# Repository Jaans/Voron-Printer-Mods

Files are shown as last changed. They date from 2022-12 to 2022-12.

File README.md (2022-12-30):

# Voron-Printer-Mods
My collection Voron printer mods or related things.

* [Bouncy Mouse](./Bouncy-Mouse)

* [CAD Model for another Angry CAM OV5648 module](./AngryCAM-OV5648-A)

* [Gantry Chain Guide](./Gantry-Chain-Guide)

* [Purge Bucket - Whopping Remix](./Purge-Bucket-Fermio-On-Kinematic)

* [Sturdy Handles for clearing 6mm panels](./Sturdy-Handles)

## Disclaimer
Content in this repository are for my own use, and not specifically for public release and not for commercial gain. 

It probably contains multiple errors, and is subject to change without notice. 

If you use anything from the repository (which you are most welcome to do), you take responsibility for the outcomes and it is up to you to determine whether it is suitable or even safe. I give no warrantees and do not take responsibility for any of your actions.

In many instances, there are designs from of existing parts and may include copies of these in my repositories for the sake of convenience, but I have tried to link to the originals and give proper credit whenever I have done so. 

If you notice a part that I did not attribute properly, I assure you this this is an oversight and not an attempt to claim anyone's work as my own. Please let me know if you notice where I have failed to properly attribute and I will get that fixed as soon as possible!

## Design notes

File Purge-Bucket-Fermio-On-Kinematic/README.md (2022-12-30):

# Purge Bucket - Whopping Remix

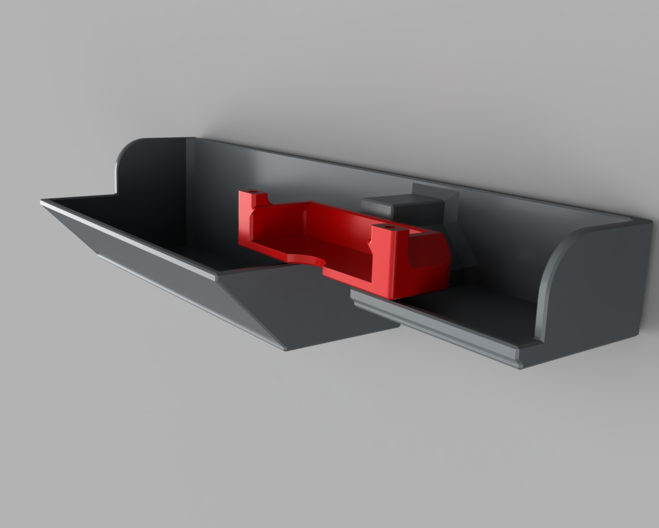
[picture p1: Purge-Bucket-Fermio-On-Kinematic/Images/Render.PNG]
Whopping Purge Bucket


These modifications are to fit my [Fermio Labs 350mmx350mm build plate](https://fermio.xyz/fermio-labs-gmbh/voron-build-plate-350-x-350-mm/) and [Whoppingpochard's Maxwell Kinematic mounts](https://uniqueprints.shop/shop/voron-2-4/voron-2-4-kinematic-bed-mount/) (Thanks @JACKT).

The CADs are shamefully adapted from the bucket design by [Dr. Dave](https://github.com/Dfdye/Voron_Mods/tree/main/Purge_Bucket_for_WP_Kinetic_Mount). 

For some reason his design didn't quite fit my setup anymore when I had to move things around a little to physically accommodate the Y offset induced by [Voron TAP](https://github.com/VoronDesign/Voron-Tap).

So, I modified them to fit.

# Models
Look in the [CAD](CAD/) and [STL](STL/) folders for the Fusion360 design and the resulting STL model.

# Build
Followed the original repo's guide.

### Printed in Polymaker PolyLite ABS.
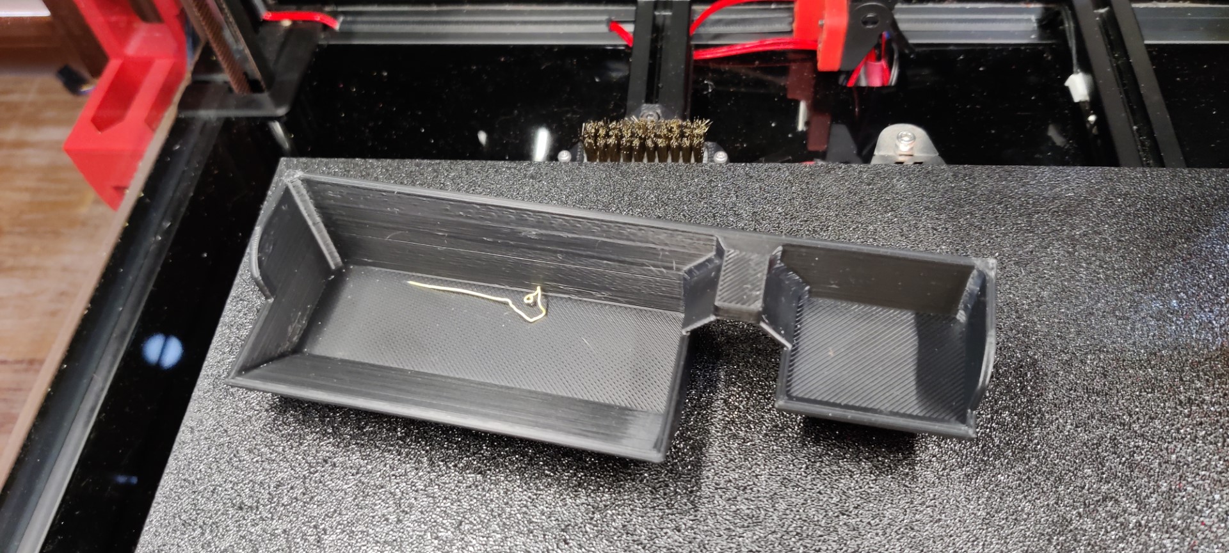
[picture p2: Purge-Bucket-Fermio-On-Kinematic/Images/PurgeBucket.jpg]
Printed


### MAG-ed and Loaded!
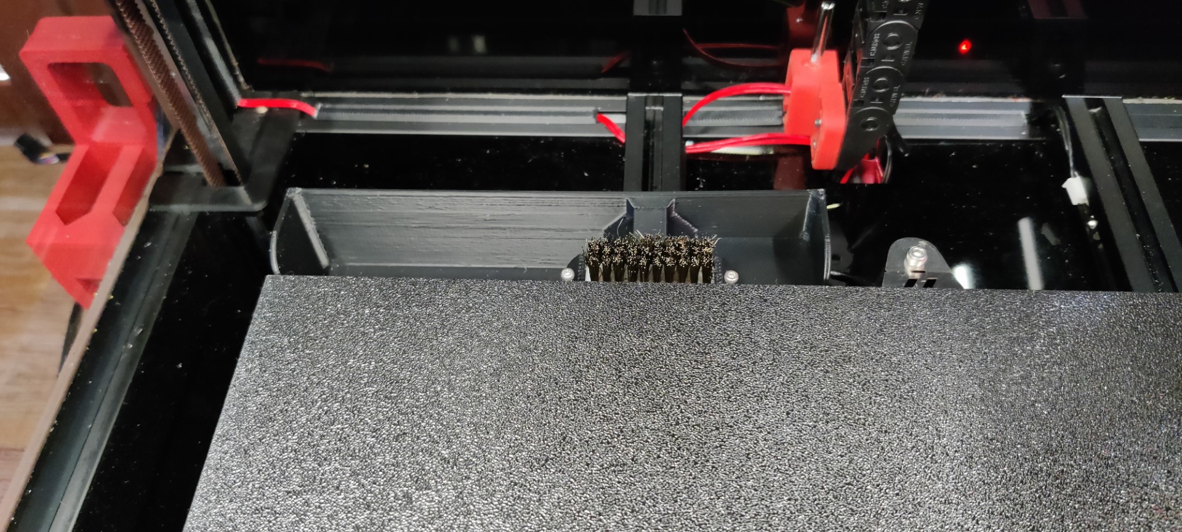
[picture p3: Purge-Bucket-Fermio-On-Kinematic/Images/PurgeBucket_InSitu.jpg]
In Situ


# Attribution
All credit goes to `Dr. Dave` and his repo over at https://github.com/Dfdye/Voron_Mods/tree/main/Purge_Bucket_for_WP_Kinetic_Mount

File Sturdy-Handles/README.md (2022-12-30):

# A 8.5mm version of Jeoje's excellent sturdy handles for my Voron v2
Replaced my panels with 6mm thick Acrylic versions and this meant that the existing [`Sturdy Handles by Jeoje'](https://github.com/VoronDesign/VoronUsers/tree/master/printer_mods/jeoje/Sturdy_Handles) didn't fit anymore :-(

So, modified them from 6mm to 8.5mm which in turn allows for clearance of 6mm panels.
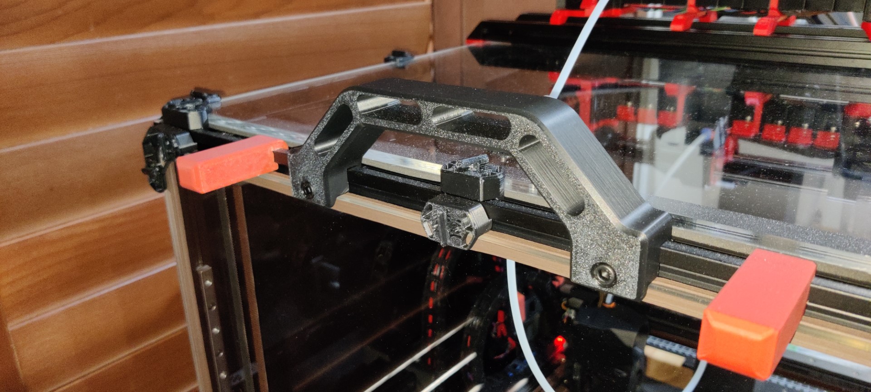
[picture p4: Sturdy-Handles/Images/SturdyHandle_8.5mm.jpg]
8.5mm Sturdy Handles


# Models
Look in the [CAD](CAD/) and [STL](STL/) folders for the Fusion360 design and the resulting STL model.

# Build
Followed the original repo's guide.
Printed in ABS with higher infill than usual, for strength.

# Attribution
All credit goes to `Joeje` and his repo over at https://github.com/VoronDesign/VoronUsers/tree/master/printer_mods/jeoje/Sturdy_Handles

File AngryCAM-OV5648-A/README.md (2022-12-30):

# Another OV5648 front cover design for Angry CAM USB

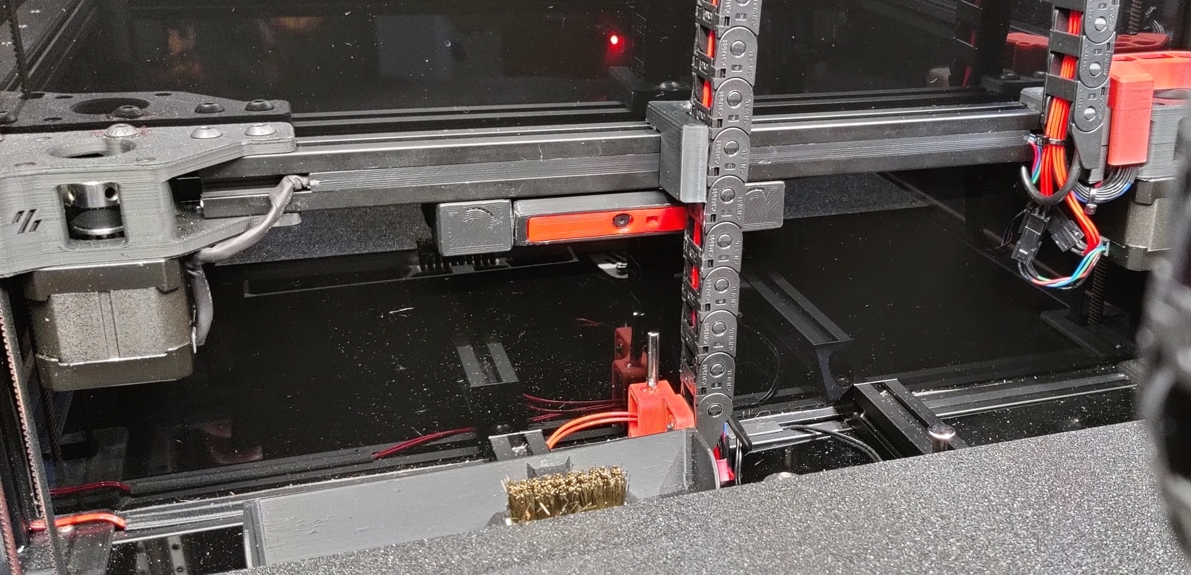
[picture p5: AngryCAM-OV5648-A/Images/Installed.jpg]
OV5648 Installed


# Camera Component Layout
There are various manufacturers of USB "stick cameras" like those for the OV5640 / OV5648 USB cameras. This repo contains CAD and STLs for fitting the layout of one of these:
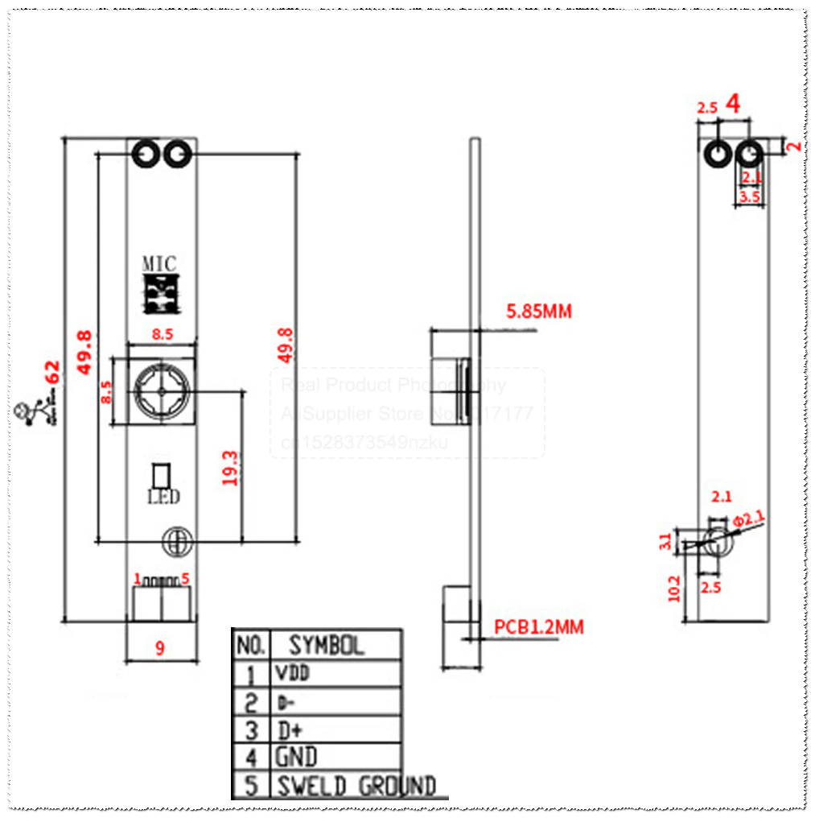
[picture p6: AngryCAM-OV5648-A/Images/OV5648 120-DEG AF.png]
OV5648 Layout


# Hardware
- The AliExpress vendor link I used was (no affiliation): 
https://www.aliexpress.com/item/1005003833993617.html?spm=a2g0o.order_list.order_list_main.5.70ce1802KScJvA

# Models
Look in the [CAD](CAD/) and [STL](STL/) folders for the Fusion360 design and the resulting STL model.

# Build

Printed in ABS to withstand the heat of my chamber.

Used default print settings, as per `#chri.kai.in`'s original [repo](https://github.com/VoronDesign/VoronUsers/tree/master/printer_mods/chri.kai.in/Angry_CAM_USB).

Side view showing clam fitment:
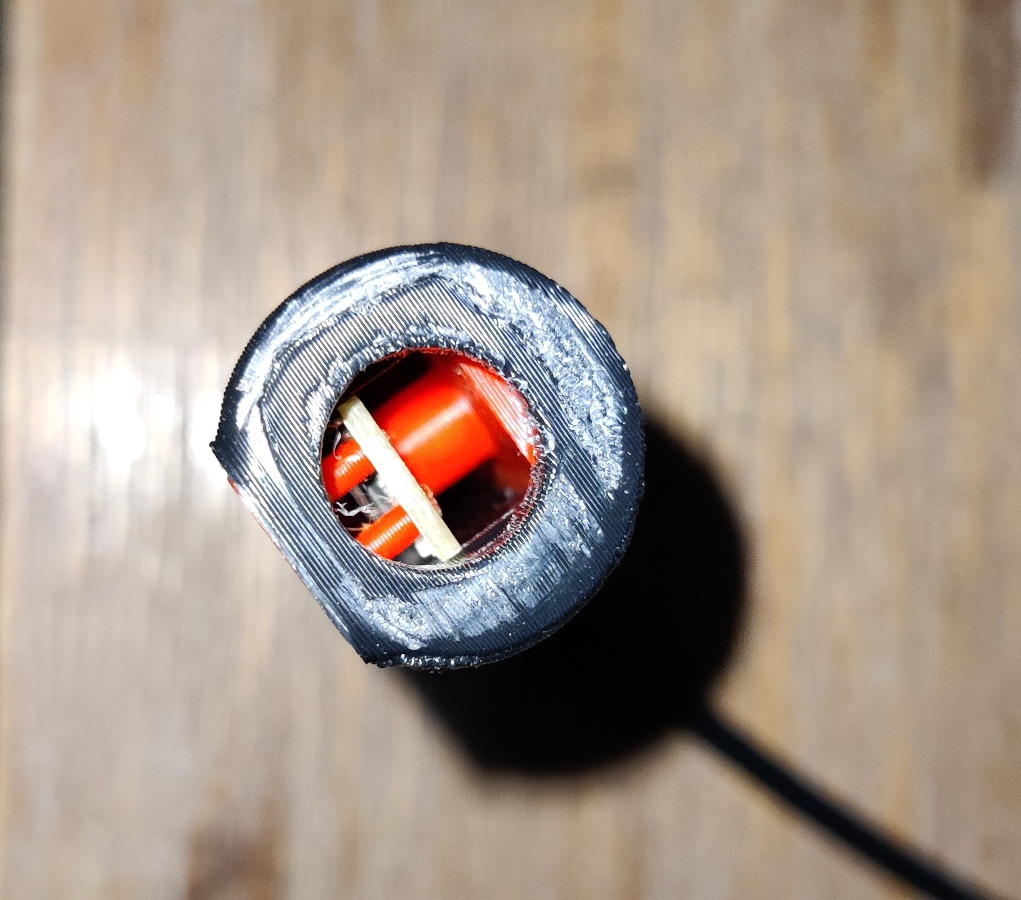
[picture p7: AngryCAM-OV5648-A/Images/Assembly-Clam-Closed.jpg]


Here's the final assembly:
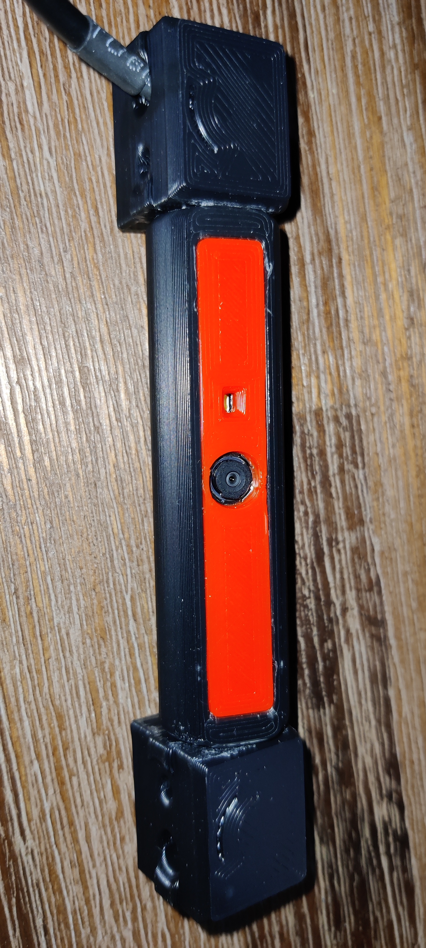
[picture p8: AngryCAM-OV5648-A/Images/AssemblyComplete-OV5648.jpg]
OV5648 Complete


# Attribution
This is not a fork or modification of `#chri.kai.in`'s excellent Angry CAM USB Voron Printer MOD. It's just an additional set of CAD & STL models for one of the different camera stick component layouts out there.

All credit goes to `#chri.kai.in` and his repo over at https://github.com/VoronDesign/VoronUsers/tree/master/printer_mods/chri.kai.in/Angry_CAM_USB

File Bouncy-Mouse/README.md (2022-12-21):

# Bouncy Mouse PCB for Voron skirt buttons
An evolution of the physical skirt button, by adding PCB to simplify wiring, soldering and physical mounting. 

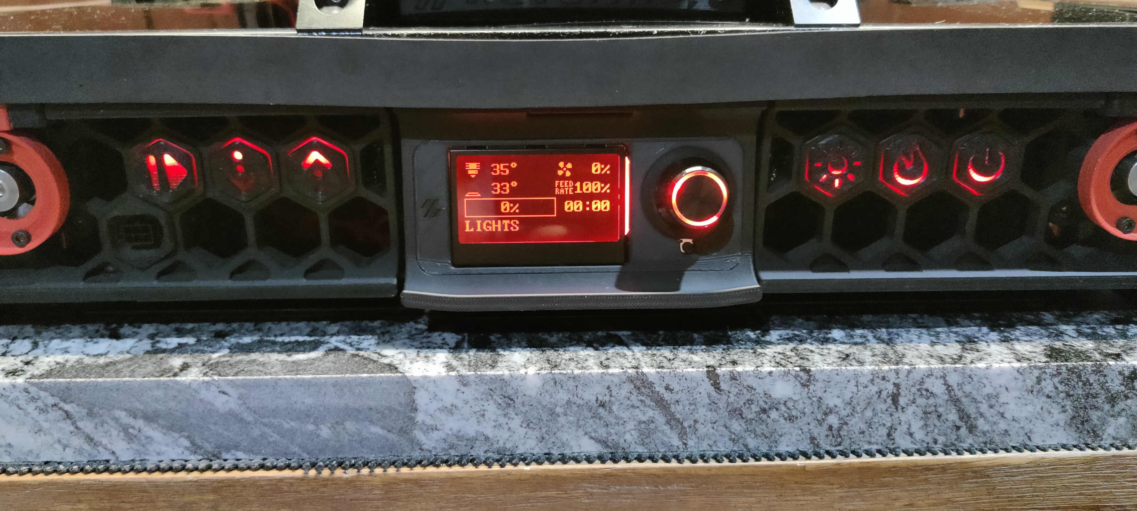
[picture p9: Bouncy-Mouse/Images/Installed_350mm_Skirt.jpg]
2x Bouncy Mouse PCB installed
  

## Credits and Attribution
This _mod_ is not original or even novel, with most concepts taken from Voron user `meteyou`'s [gcode_buttons](https://github.com/VoronDesign/VoronUsers/blob/master/legacy_printers/printer_mods/README.md) and adapted to fit my needs after trial and error experiences.

Thanks to `meteyou` and everyone else who had some incarnation of skirt buttons for the Voron. Thanks to `MakerBogans` Australia 3D printer community for being friendly and supportive human beings.

<br/>

# What are skirt buttons / G-Code buttons?
The idea is about having the convenience of direct interaction with physical buttons that perform a desired action upon pressing / releasing them. For example, pressing button `X` should instruct the print to turn on/off the internal LED light. (Insert your imagination here - mine sucks.)

The idea is not novel in any way and `Bouncy Mouse` is intended to help you build your own "custom" keyboard that can be installed in your Voron skirt, and then to connect that to your Raspberry PI / other GPIO interface and have it execute G-Code or macros.

Some users even replace / remove their display in favour of this.

Here's the `Bouncy Mouse` 3-Key PCB (v1 is pictured - v2 is current but with minor tweaks):
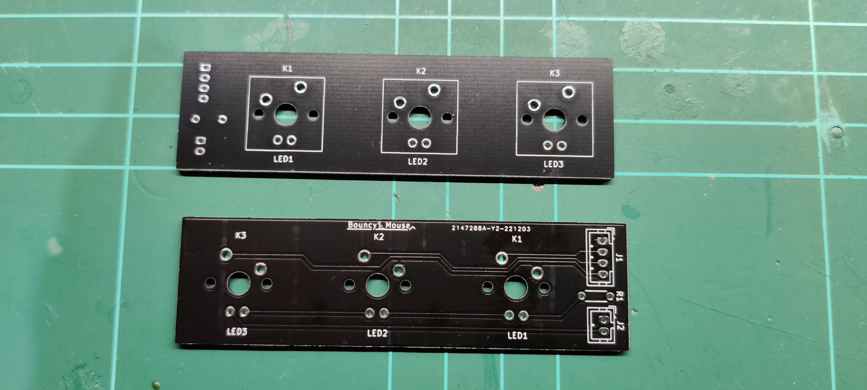
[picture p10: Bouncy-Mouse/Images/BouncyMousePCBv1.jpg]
Bouncy Mouse PCB v1


Holds up to three CherryMX key switches (LED optional)

## Some known uses for G-Code buttons
- Pause / Resume an active print.
- Turn on/off/push-to-peek chamber LED lights.
- Turn on/off fans.
- Multi-material control (like ejecting filament in ERCF) 
- Start your Pre-heat / Warm-up routine
- Graceful shutdown of Printer Software (e.g. Klipper / Raspberry PI Operating System)
- Take a photo from printer CAM
- Home your printer

<br/>

## Do I need Bouncy Mouse?
No, you don't. You can use `meteyou`'s MOD and wire things directly - nothing wrong with it.

I created this because I found the soldering of wires to the switches and LEDs hard and fragile (I solder poorly - it's a hobby for me). Found the PCB held it all together much more firmly and rigidly.

<br/>

## I'm in - which one do I need?
The hexagonal voids in the Voron skirts for v2.4, Trident and Switchwire are the same size and have the same spacing between them - there are just less or more voids (for keys).

At the moment there are 3 variations, basically allowing for 1, 2 or 3 key switches.

> Thanks @karlOS and everyone else for your input with the below. The table indicates the _largest_ size model that would still fit for the different Voron models.

| Size  | Switchwire | Trident | 2.4 |
|---:|:---:|:---:|:---:|
|  SW | 3-Key | -- | -- |
| 250mm | -- |  3-Key  |  1-Key  |
| 300mm | -- |  3-Key  |  2-Key  |
| 350mm | -- |  3-Key  |  3-Key  |

There is nothing stopping you from using a smaller 1-Key PCB, even if a larger 3-Key version could fit.

## Bill of Materials (BOM)
The hexagonal voids in the Voron skirts are the same size and spacing across the different Voron v2 size models (250mm vs. 300mm vs. 350mm) - there are just less or more voids (and thus keys).

### PCB Options
Here are the current variations. Refer to [above section](#im-in---which-one-do-i-need) to decide which one to use
* `3`-Key PCB

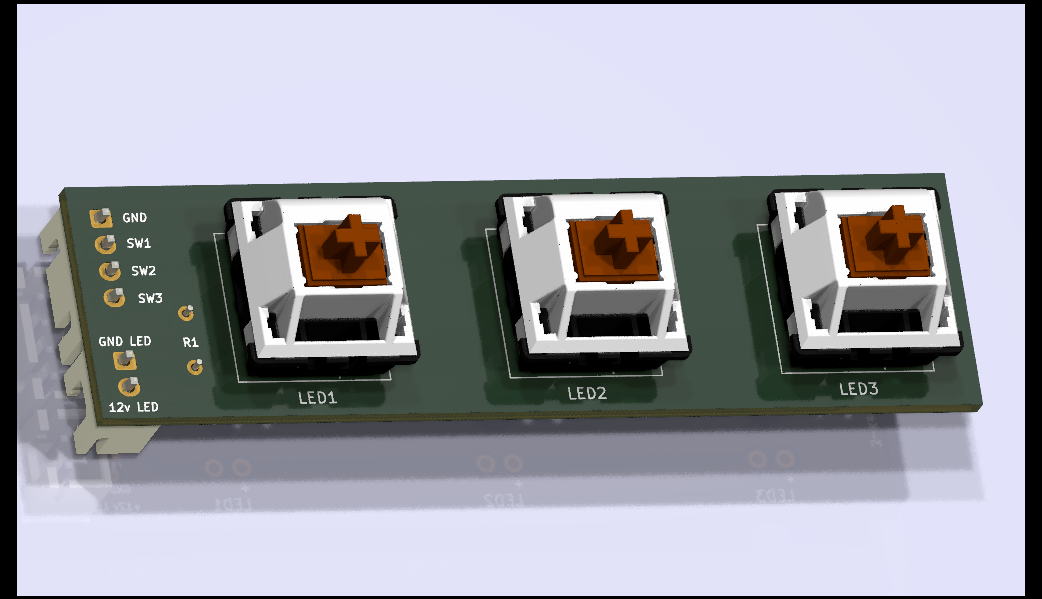
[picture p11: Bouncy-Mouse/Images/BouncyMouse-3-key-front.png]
    
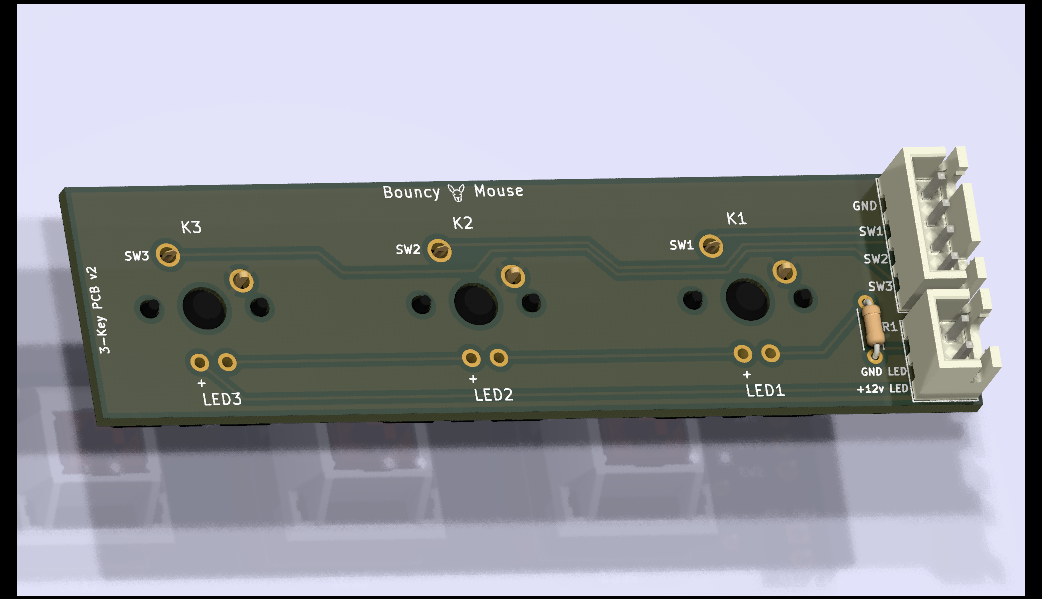
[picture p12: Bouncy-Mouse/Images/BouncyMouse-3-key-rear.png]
    

* `2`-Key PCB

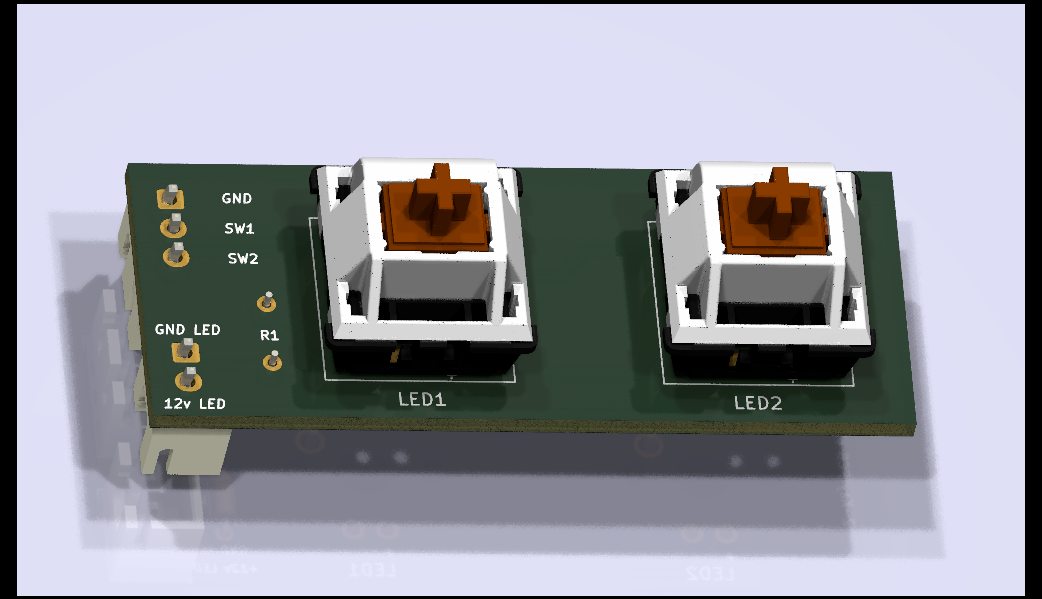
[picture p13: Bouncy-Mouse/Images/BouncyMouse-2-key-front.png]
    
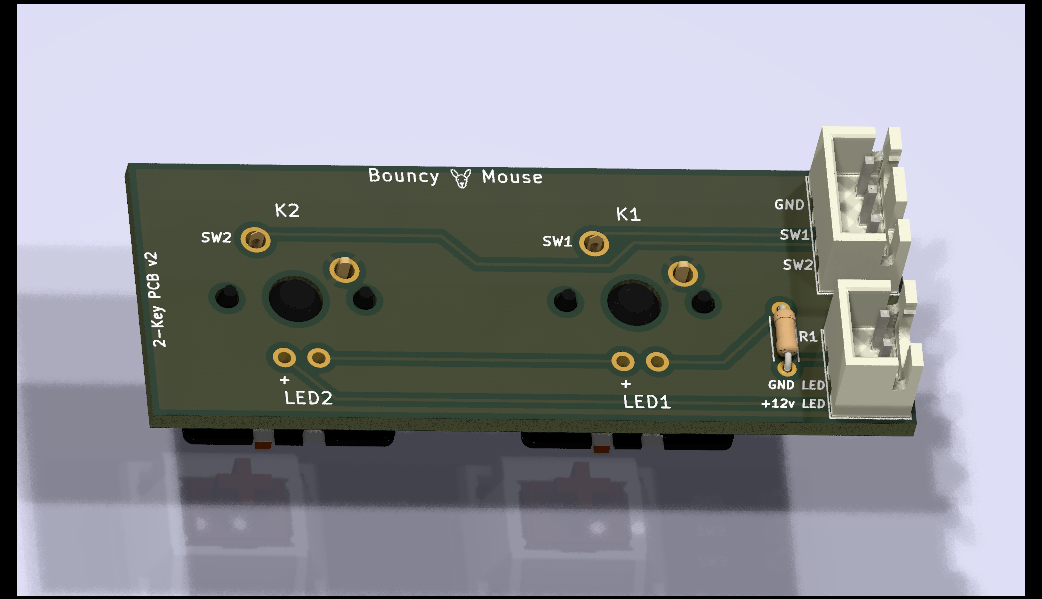
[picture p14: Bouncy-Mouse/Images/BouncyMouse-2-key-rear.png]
    

* `1`-Key PCB

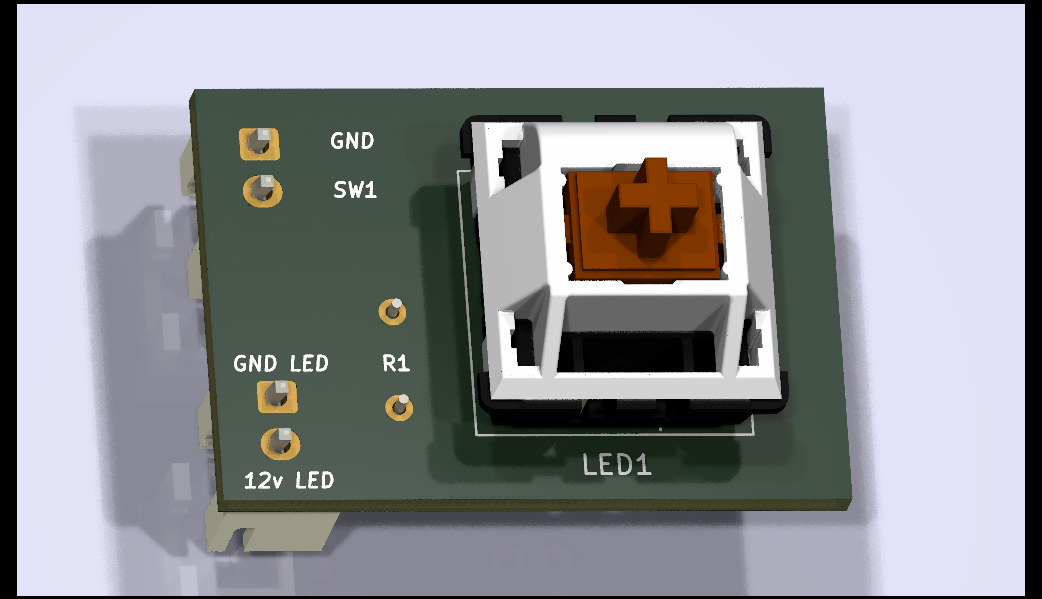
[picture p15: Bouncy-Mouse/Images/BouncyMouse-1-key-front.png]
    
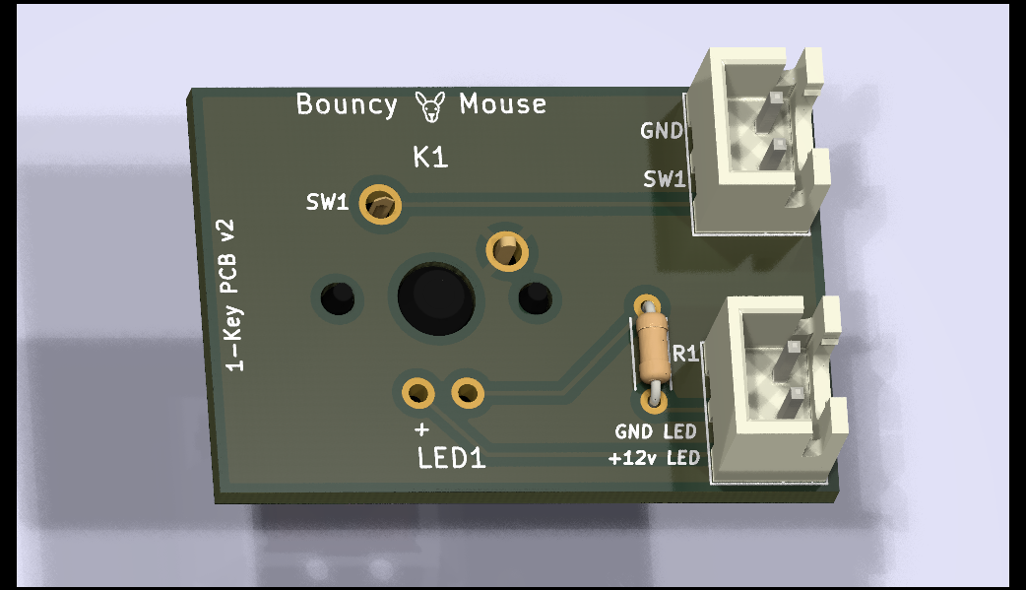
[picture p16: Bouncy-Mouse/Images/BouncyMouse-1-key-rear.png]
    

<br/>

### For each PCB, where `N` is the number of keys:
* `N`x CherryMX switches

* `N`x Printed part set
    * Hexagon Key Cap

    * Hexagon Key Shell

    * Hexagon Shell Retention Clip

* `N`+1 PIN JST XH through the hole / PCB mount receptacle (marked as J1 on PCB)

* `N`+1 PIN JST XH crimp connector housing

* `N`+1 PIN JST XH crimp connector female pin

* AWG 28 wiring long enough to reach connection points (recommend fitting length to size at point of installation)

<br/>

### Optional LEDs
The LED key backlight is optional. 

The LEDs require a current limiting resistor is required or you'll blow them. This is what R1 (marked on PCB) is for.
The Ohm size of R1 depends on your chosen configuration.

Key points to remember regarding R1:
* PowerSupply Voltage matters 12v vs. 24v.
* Number of LEDs matter.
* 12v is likely a minimum for 3 LEDs. 

A handy resource for calculating an appropriate value for R1 can be found [here](https://ledcalculator.net/#p=12&v=1.6&c=16&n=3&o=s). 
That link is pre-configured for 3 LEDs, a 12v Power Supply and typical 3mm Polulu LED forward voltages of 1.6v-1.8v.

If you are having difficulty getting these figured out, you are welcome to enquire with me (#Jaans) in the MakerBogans discord.

Here's the BOM for the LED portion of the PCB:
* 2 PIN JST XH through the hole / PCB mount receptacle (marked as J2 on PCB)

* 2 PIN JST XH crimp connector housing

* 2 PIN JST XH crimp connector female pin

* R1 - Resistor values

| Number of LEDs | Power Supply | LED forward voltage | LED current rating | R1 |
|:---:| ---:| ---:| ---:| ---:|
| 3| 12v| 1.6v| 16mA| 430-470ohm|
| 2| 12v| 1.6v| 16mA| 530-560ohm|
| 1| 12v| 1.6v| 16mA| 640-680ohm|
| - | - | - | - | - |
| 3| 24v| 1.6v| 16mA| 1100-1200ohm|
| 2| 24v| 1.6v| 16mA| 1200-1300ohm|
| - | - | - | - | - |
| 1| 5v| 1.6v| 16mA| 200-220ohm|

```
    Resistor ranges given (instead of absolute) to help use available 
    stock. Lower values will be more for brighter but also shorter life.

    I'm not an electronics engineer - so please validate the above for 
    yourself. Suggest you create a little test circuit to see if your 
    chosen LEDs and R1 value works. 
    
    Although this is generally safe and *should* at worst only blow the
    LED, bad things can happen - please refer to disclaimer section.
```
<br/>

## How to build
I see it as 4 main stages. 
Refer to each of the following pages for more detailed information:
1. [Print parts](./Stage1.md)

    Button shell, hexagon holder, key cap with icon.
    
    Click [here](./Stage1.md) to view page about this section.

    <br/>

2. [Physical build](./Stage2.md)
    
    Assemble PCB, Button, LED, Wires, Crimps, Solder, etc.
    
    Click [here](./Stage2.md) to view page about this section.

    <br/>

3. [GPIO PIN setup](./Stage3.md)

    I use a Raspberry PI 4B and configure pins as input with pull-up resistor enabled.

    Click [here](./Stage3.md) to view page about this section.

    <br/>

4. [Klipper setup](./Stage4.md)

    What to do when GPIO pin has been triggered.

    Click [here](./Stage4.md) to view page about this section.

<br/>

## Disclaimer
The ideas and suggestions here are meant in good faith, but offer no warranty and accepts no liability for any actions taken by you directly or indirectly, taken in part or in full from the content in this repository.

You acknowledge that if you wire or solder incorrectly, use the wrong polarity or voltage, or inappropriate resistor sizes, create short-circuits, etc. then you can damage not only these components but also the connected devices like your MCU controller or GPIO device like Raspberry PI. Soldering irons can cause severe burns and start fires - you are assumed competent to perform whatever action you decide. Don't take on this project if you are not comfortable with holding yourself responsible, working with electronics, soldering irons, etc. 

*Plain English: You acknowledge you are responsible for your actions and don't hold me liable for anything whatsoever.*

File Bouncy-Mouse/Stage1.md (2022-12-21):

# Stage 1 - Print parts
Look in the STL folder and print the following, 1x for each key:
* Hexagon Key Cap

* Hexagon Shell

* Hexagon Retention Clip (I'd print a few more incase they break)

If you are using 3 keys, then you need to print 3 of each.

*Pro-tip: Do yourself a favour now, and use a file or similar to smooth out any edges on the shell inner walls and key caps. If you don't you might get keys sticking.*

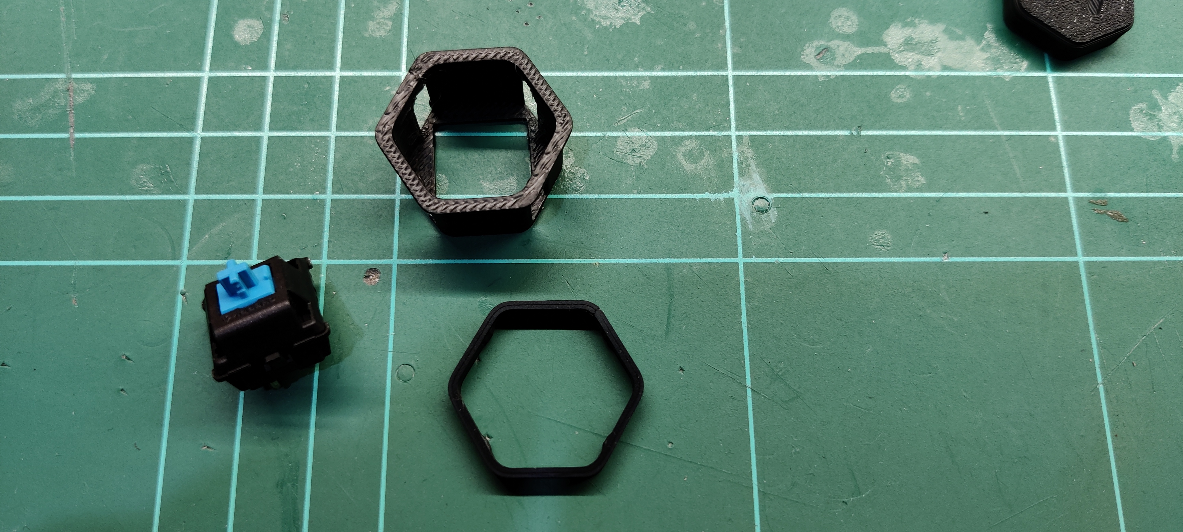
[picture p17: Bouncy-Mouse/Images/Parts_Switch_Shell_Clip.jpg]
Parts to put together


Here's some sample prints
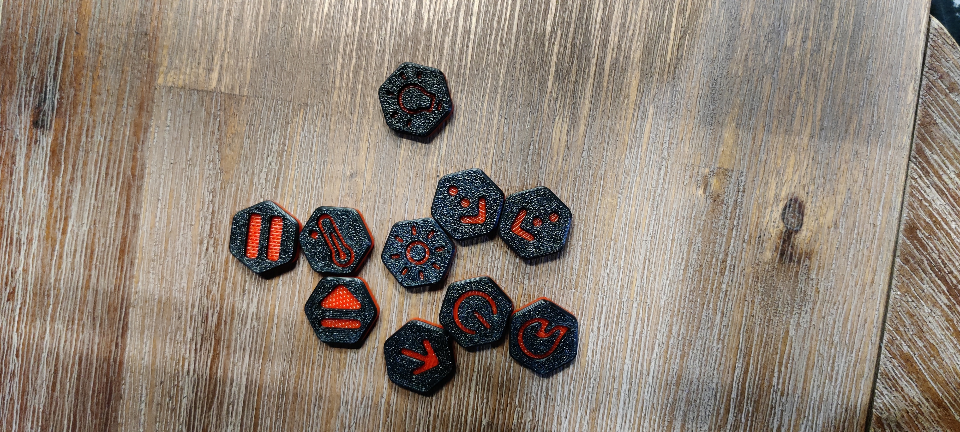
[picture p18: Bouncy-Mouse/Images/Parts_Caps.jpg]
Parts to put together


## Print settings
- Nothing special. Using standard Voron part print settings should work fine.

- ABS used in the photos, but I suppose PLA should work too as its not a high temperature environment. I prefer not to use PLA (which degrades over time) for anything structural.

- Consider level of detail on buttons and changing colors for backlight to come through. I'll add some more key caps over time.

<br/>

### Next - Stage 2 - Physical Build : Click [here](./Stage2.md)

<br/>

### Back to HOME : Click [here](./README.md)

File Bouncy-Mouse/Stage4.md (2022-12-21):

# Stage 4 - Klipper setup

Last but not the least we need to tell Klipper about the GPIO pins and create G-Code buttons for them.

I chose to separate my various configuration sections out into separate `.cfg` files like `buttons.cfg` in this case. You do you - that's beyond the scope of this guide.

Here's the content of my [buttons.cfg](Klipper/buttons.cfg) file. Adapt it to your needs:

```
# Push Button RPI Pins
#########################
# Configure the pins as input pins with pull up resister enabled.
# Update /boot/config.txt to configure GPIO pins at startup.
# https://www.raspberrypi.com/documentation/computers/config_txt.html#what-is-config-txt
#########################

[gcode_button Button_Z_Up]
pin: ^!rpi:gpio17
press_gcode: 
    M117 Z-UP
release_gcode:
   _ZUP            # Custom G-Code macro

[gcode_button Button_Z_Down]
pin: ^!rpi:gpio27
press_gcode: 
    M117 Z-DOWN
release_gcode:
   _ZDOWN          # Custom G-Code macro

[gcode_button Button_Pause_Resume]
pin: ^!rpi:gpio22
press_gcode: 
    M117 PAUSE-RESUME
    {% if printer.pause_resume.is_paused %}
        M117 Resuming...
        M118 Resumed via skirt button
        RESUME
    {% else %}
        {% if printer.idle_timeout.state != "Printing" %}
            M117 Not printing.
            M118 Cannot pause - not currently printing.
        {% else %}
            M117 Pausing...
            M118 Paused via skirt button
            PAUSE
        {% endif %}
    {% endif %}
release_gcode:

[gcode_button Button_Lights]
pin: ^!rpi:gpio19
press_gcode:
    {% if printer['output_pin caselight'].value %}
        SET_PIN PIN=caselight VALUE=0
        status_off
    {% else %}
        SET_PIN PIN=caselight VALUE=0.4
        status_ready
    {% endif %}
release_gcode:

[gcode_button Button_Warmup]
pin: ^!rpi:gpio26
press_gcode: 
    M117 WARM UP
    WARM_UP         # Custom G-Code macro
release_gcode:

[delayed_gcode _SHUTDOWN_MACHINE]
gcode:
    {% if printer.idle_timeout.state != "Printing" %}
        SET_PIN PIN=caselight VALUE=0                       # Caselight off
        status_off                                          # Stealth Burner LED off
        {action_call_remote_method("shutdown_machine")}     # Invoke moonraker API to shutdown
    {% else %}
        M117 No shutdown - busy printing
        M118 No shutdown - busy printing
    {% endif %}

[gcode_button Button_Shutdown]
pin: ^!rpi:gpio21
press_gcode: 
    M117 Shutdown...
    M118 Shutdown via skirt button...
    UPDATE_DELAYED_GCODE ID=_SHUTDOWN_MACHINE DURATION=1
release_gcode:
```

<br/>

### Back to HOME : Click [here](./README.md)

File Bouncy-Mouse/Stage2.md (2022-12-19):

# Stage 2 - Physical Build
Click this link to see [image from `meteyou`'s MOD](https://github.com/VoronDesign/VoronUsers/tree/master/legacy_printers/printer_mods/meteyou/gcode_buttons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) that shows an exploded view on how the parts fit together.

What follows below, combines that with the PCB.

Parts to put together

<br/>

## A - Mate the Switch to the Shell
 `CherryMX key switch` fits into the `Hexagon Shell`. 
 
 Take note of the orientation of the switch and ensure all keys have the same orientation. 
 
 The Caps only fit 0 / 180 degrees orientation and cannot be used at 90 angle. So just make sure your keys are the same. 

Depending on how you mount the `Bouncy Mouse` PCB, you may need to slot them upside down (or at 180 degrees). 
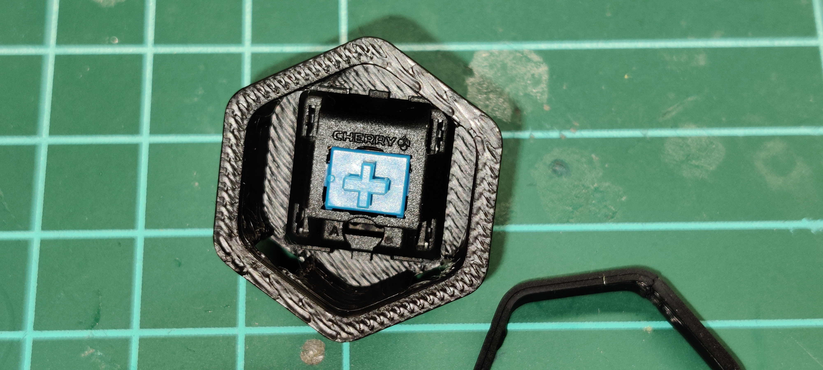
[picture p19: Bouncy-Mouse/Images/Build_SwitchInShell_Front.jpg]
Switch in Shell Front

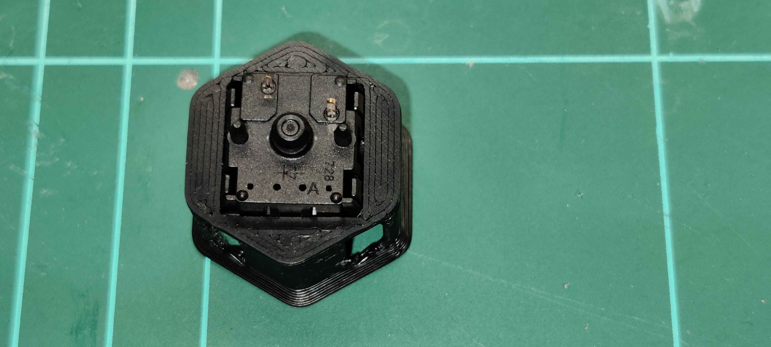
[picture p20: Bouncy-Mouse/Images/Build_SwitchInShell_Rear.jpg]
Switch in Shell Read


## B - Mate the Shell to the Skirt
The `Hexagon Shell` slides into the skirt hollow from the front (outside). 
The image below includes the retention clip already applied (from step C below).
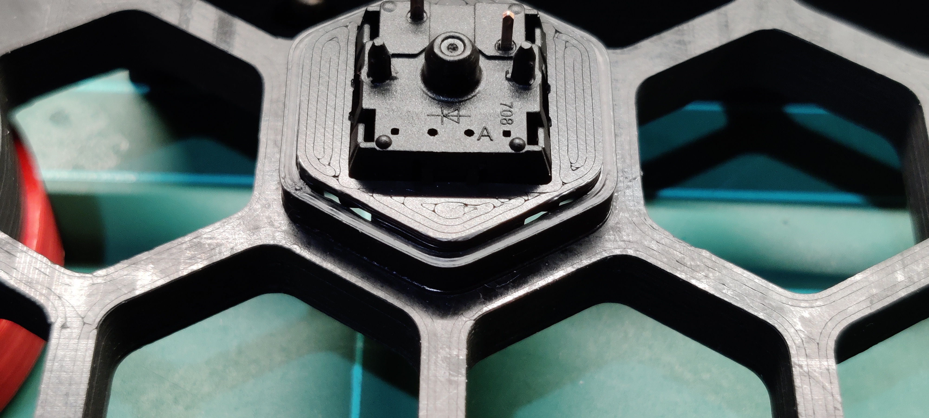
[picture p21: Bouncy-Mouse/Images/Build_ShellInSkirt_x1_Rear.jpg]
Shell in Skirt Rear


## C - Use retention clip to keep Shell in the Skirt
The `Hexagon Retention Clip` slides onto the shell from the back (inside) and holds it into place so it doesn't slide out.

*Take note the orientation of this clip as it has little bumps/tabs that need to align with the slots/holes of the shell*
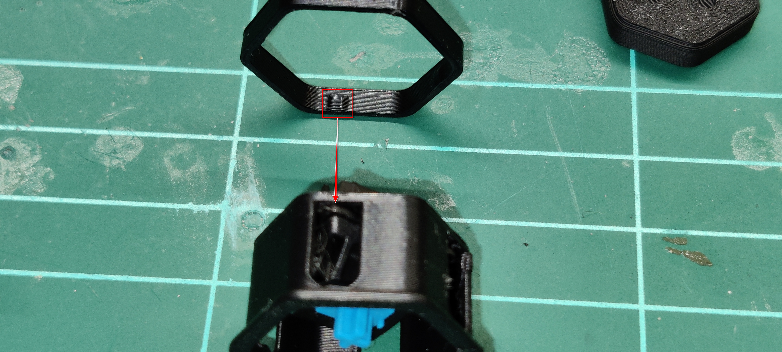
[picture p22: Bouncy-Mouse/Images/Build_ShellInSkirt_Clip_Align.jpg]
Shell retention alignment

Here's the whole set front and back installed:
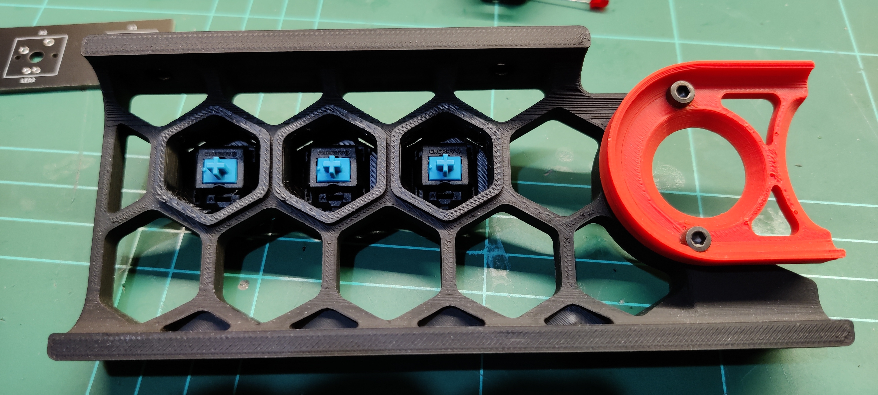
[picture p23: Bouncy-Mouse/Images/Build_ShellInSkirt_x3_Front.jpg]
Shells in Skirt Front

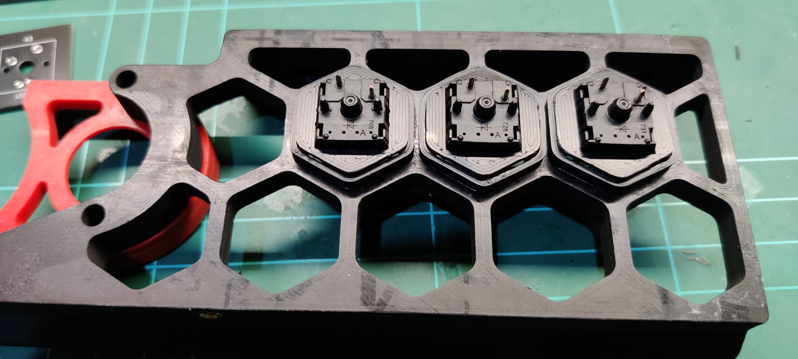
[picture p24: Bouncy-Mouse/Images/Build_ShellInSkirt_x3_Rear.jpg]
Shells in Skirt Rear


## D - Install and Solder Resistor R1 and JST connectors
*Important to add the connector and resistor components to the PCB __before__ soldering the PCB to the buttons in step F below*

Insert the Resistor into R1 (polarity doesn't matter) and also the JST connectors:
Build_PCB_Connectors_and_Resistor
Take note of the side of the PCB here - these components come through from the back of the PCB and are soldered on the front. 

If you are not using LED for back-lighting, then you can skip adding the 2-pin JST connector for position J2

*While v2 of the PCB has slightly different spacing, populating the components are the same.*

View from front of PCB:
Insert connectors and resistor

Now solder these pins down on the front (please ignore my crappy soldering skills).
Solder connectors and resistor

## E - Attach PCB to Skirt assembly
This was a snug fit but I didn't need to force it. Depending on your print accuracy you may need some patience - just don't bend the pins of the key switch, and avoid cracking the shells.

Here's a side on view (taken during test fit before soldering connectors):
Attach PCB to skirt assembly side view

## F - Add LED (Optional)
*The LED is for back-lighting of the `Hexagon Key Cap` and is optional.*

Insert the 3mm LED of your choice in from the front, through the Key Switch body:
LEDs in switch
Take note of the polarity of the LED and match with the polarity on the PCB (polarity symbols added to v2 PCB - not shown above).

## G - Solder the sandwich
This might be a good time to double check any polarity and whether you have already soldered in your JST connectors (J1/J2) and resistor (R1), __before__ soldering the switches and LEDs.

Final assembly - rear

And from the front:
Final assembly - front

## H - Install

Installed in the frame:
Installed - 1

The connector J2 exclusively powers the LEDs. This independent of J1 and do __NOT__ share ground (GND) with the ground (GND) of the switches.

Pin 1 of connector J1 is the ground (GND) for the GPIO pins, and is shared with each of the keys in parallel. This means you don't have to provide a separate ground for each key GPIO and also that not all key slots have to be used. You can populate just K1 or just K2 for example.

## I - Important note about key LEDs and resistor R1
The LEDs are backlight to the key caps and are optional. They are wired independently of the switches circuit, and connect in series.

The R1 resistor value of between 430-470ohm was selected based on having 3x 3mm LEDs populated and connected to a 12v supply (from BTT Octopus 1.1). 

If you use anything other than:
* 12v supply
* fewer / more than 3x LEDs
* non BOM components (like LEDs that do not have a forward voltage of around 1.6v - 1.8v)

  **then you need to adjust your R1 value accordingly**.

> Refer to the BOM section for details on selecting a suitably sized resistor for R1.

<br/>

### Next - Stage 3 - GPIO PIN setup : Click [here](./Stage3.md)

<br/>

### Back to HOME : Click [here](./README.md)

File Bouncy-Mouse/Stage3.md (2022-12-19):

# Stage 3 - GPIO PIN setup

## Create JST crimped wires
You can also go ahead an measure out some wire lengths that fit your layout.
The number of wires will need to fit your selection of `N`-Key PCB and LEDs.

The one end of wire loom has the JST XH female pin connector crimped and connects to the PCB. 

I'm using my Raspberry PI for GPIO pins and so I chose to crimp Du-Pont style connectors on the other end to more easily connect to the PI headers.

 Both PCBs installed and wired up to PI:
Installed - 2

## GPIO PIN selection
For my personal configuration I used the following GPIO pins from my Raspberry PI 4 (that I had available since I use an accelerometer). 

> You may need to use different PINs - if so, remember to update the pin mappings - refer further down below and STAGE 4.

My left keyboard:
- GPIO17
- GPIO27
- GPIO22

and my right keyboard:
- GPIO19
- GPIO26
- GPIO21

**IMPORTANT:** GPIOxx is __not__ the same as PINxx - refer image below. The yellow highlighted pins are for the GPIO buttons.

GPIO Assignment
> Attribution: LinuxHint.com owns the original image

The above also shows which ground pins I used.

## Raspberry PI configuration
We need to tell the Raspberry PI that we want to use the above GPIO pins as INPUT pins (not the default), and also to enable the PULL-UP resistor so that when we close the circuit to ground via the PCB switch, the state can change and be detected.

This is pretty simple to do, but requires a but of Linux / Raspberry PI OS know how.

There should be a lot of additional resources available on how to edit / modify a file on the PI, so I won't rehash that here. You want to either SSH into your PI and use an editor to modify the file, or you could do so remotely via SCP tool like WinSCP (if you are on Windows).

What we want to do is edit the `/boot/config.txt` file to configure GPIO pins at startup:

Raspberry PI - GPIO Startup

This way the PIN configuration is retained after reboots of the PI.

_**Note:** Remember to adjust the GPIO pins referenced to match your selection._

<br/>

### Next - Stage 4 - Klipper setup : Click [here](./Stage4.md)

<br/>

### Back to HOME : Click [here](./README.md)

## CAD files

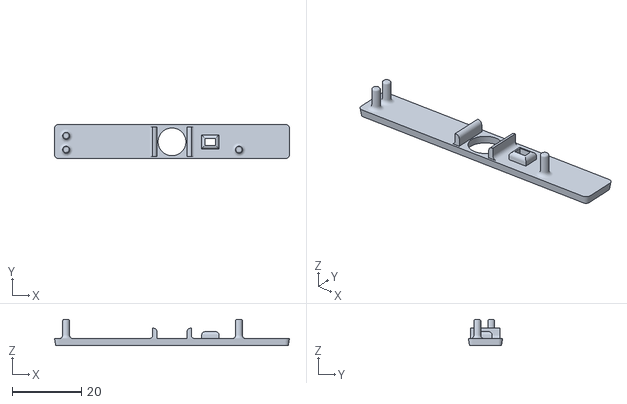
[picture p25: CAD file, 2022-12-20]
AngryCAM-OV5648-A/STL/Front_Cover_OV5648_120DEG_AF v13.stl
67.7 x 9.91 x 7.50

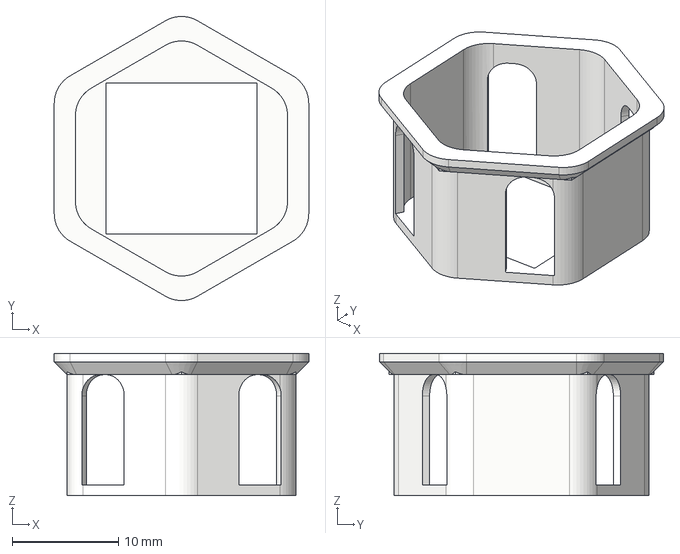
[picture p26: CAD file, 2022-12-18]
Bouncy-Mouse/CAD/base.step
24.0 x 26.8 x 13.4 mm

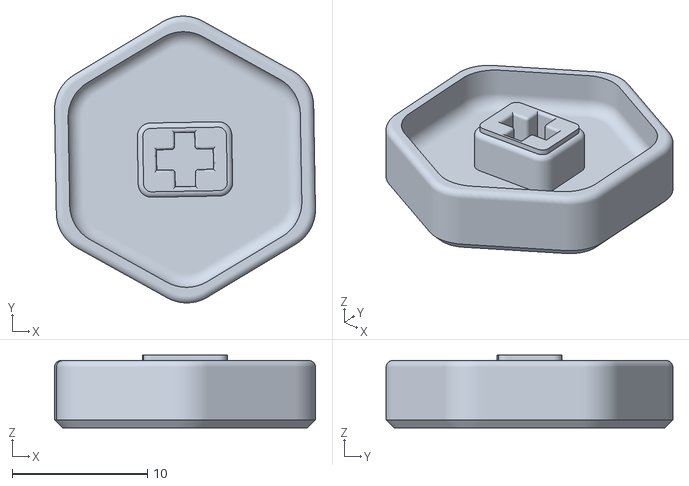
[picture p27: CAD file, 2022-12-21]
Bouncy-Mouse/STL/cover-flame v2.stl
19.3 x 21.2 x 5.40

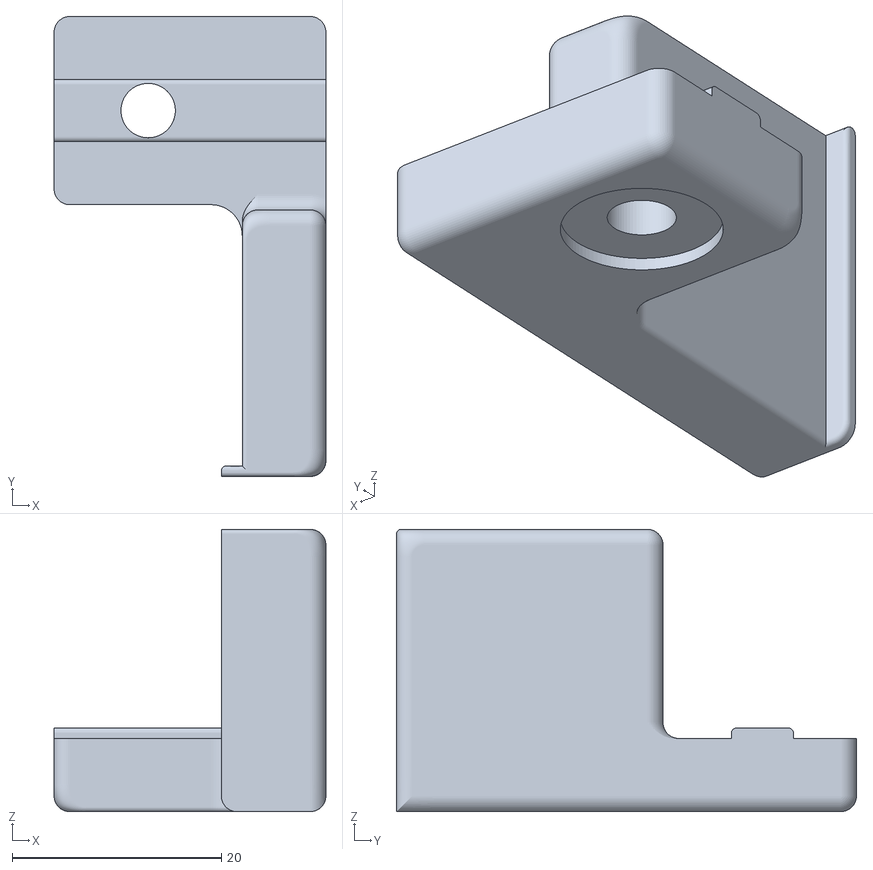
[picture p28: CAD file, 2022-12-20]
Gantry-Chain-Guide/STL/Cable Chain Guide for Centre Gantry v9.stl
26.0 x 44.0 x 27.0

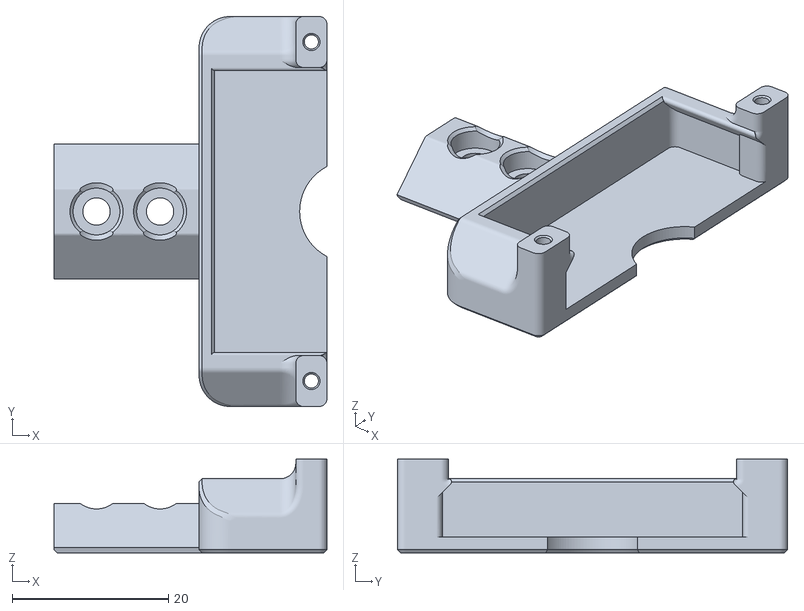
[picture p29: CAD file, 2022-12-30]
Purge-Bucket-Fermio-On-Kinematic/STL/Brush Holder Sheet Stop -- Mod.stl
35.0 x 50.0 x 12.0

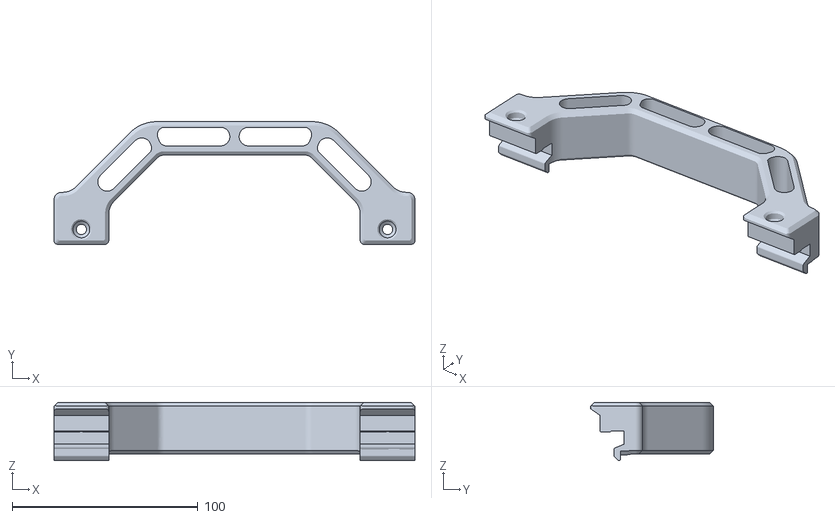
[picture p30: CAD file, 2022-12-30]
Sturdy-Handles/STL/sturdy_handles 8.5mm.stl
194.3 x 66.0 x 31.4

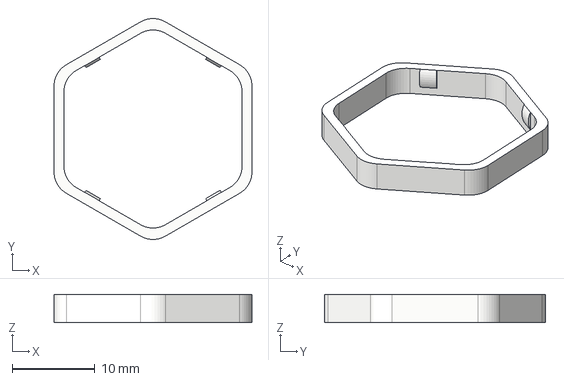
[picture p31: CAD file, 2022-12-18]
Bouncy-Mouse/CAD/lock.step
24.0 x 26.8 x 3.40 mm

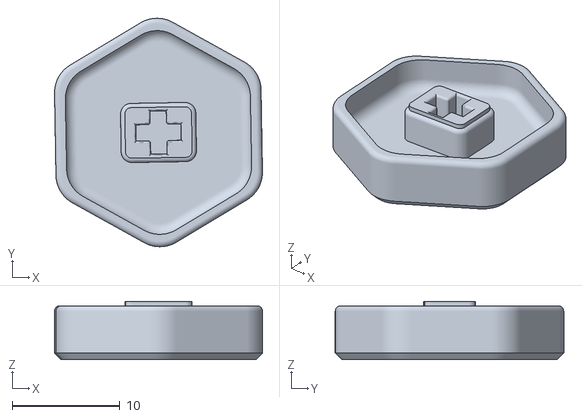
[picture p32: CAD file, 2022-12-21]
Bouncy-Mouse/STL/deepcuts/cover-camera v2.stl
19.3 x 21.2 x 5.40

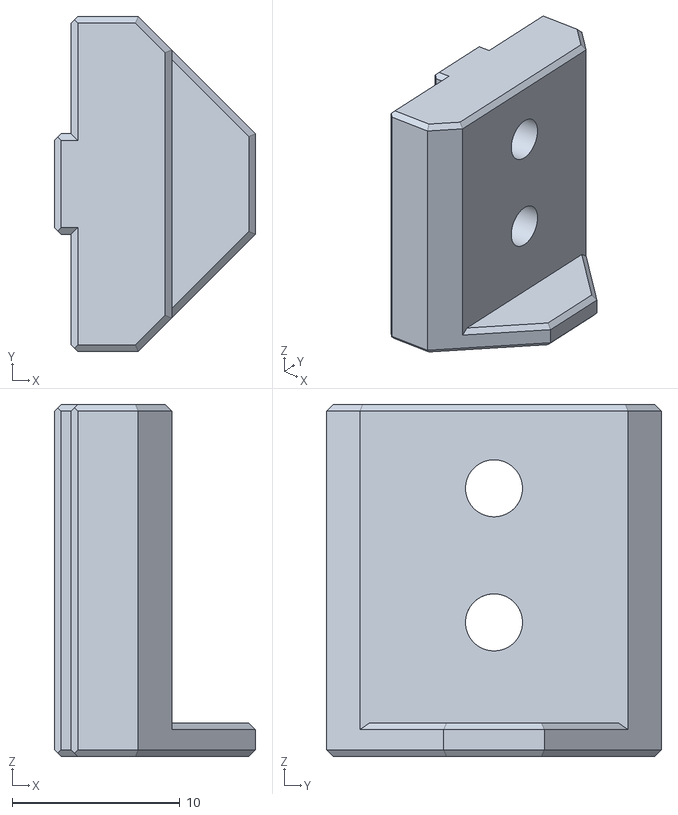
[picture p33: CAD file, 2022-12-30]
Purge-Bucket-Fermio-On-Kinematic/STL/Brush Mount Spacer Shortened.stl
12.0 x 20.0 x 21.0

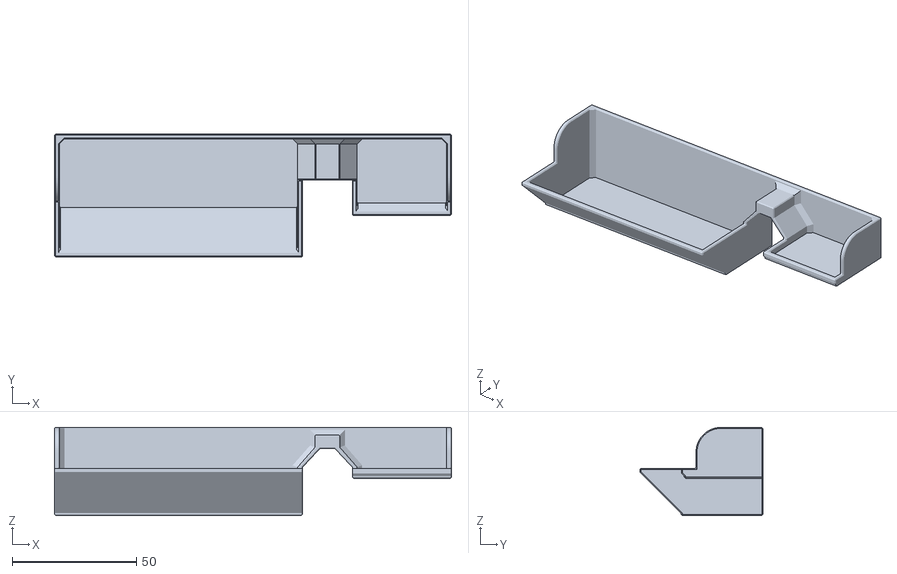
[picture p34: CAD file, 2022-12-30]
Purge-Bucket-Fermio-On-Kinematic/STL/Purge Bucket--Large Vertical Shortened.stl
160.0 x 49.5 x 35.5

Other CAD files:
Bouncy-Mouse/STL/deepcuts/cover-pause-play v2.stl
Bouncy-Mouse/STL/cover-camera v2.stl
Bouncy-Mouse/STL/cover-pause v2.stl
Bouncy-Mouse/STL/deepcuts/cover-arrow-vertical v4.stl
Bouncy-Mouse/STL/cover-light-2 v2.stl
Bouncy-Mouse/STL/deepcuts/cover-pause v2.stl
Bouncy-Mouse/STL/cover-pause-play v2.stl
Bouncy-Mouse/STL/deepcuts/cover-light-2 v2.stl
AngryCAM-OV5648-A/CAD/Front_Cover_OV5648_120DEG_AF v13.f3d
Bouncy-Mouse/CAD/cover-arrow-vertical v4.f3d
Bouncy-Mouse/CAD/cover-arrow-vertical-dot-dot v2.f3d
Bouncy-Mouse/CAD/cover-camera v2.f3d
Bouncy-Mouse/CAD/cover-empty v2.f3d
Bouncy-Mouse/CAD/cover-flame v2.f3d
Bouncy-Mouse/CAD/cover-light v2.f3d
Bouncy-Mouse/CAD/cover-light-2 v2.f3d
Bouncy-Mouse/CAD/cover-pause v2.f3d
Bouncy-Mouse/CAD/cover-pause-play v2.f3d
Bouncy-Mouse/CAD/cover-power v3.f3d
Bouncy-Mouse/CAD/cover-preheat v2.f3d
Bouncy-Mouse/CAD/cover-temp v2.f3d
Bouncy-Mouse/STL/base.stl
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

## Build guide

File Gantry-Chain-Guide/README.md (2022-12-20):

# Yet Another Chain Guide

I needed a chain guide I could put on the back gantry of my Voron v2.4 350mm to keep the drag chain from moving/folding over into the view of my gantry mounted camera.

Couldn't find what I needed, so modelled my own variation.

The CAD is included in this repository, so feel free to adjust it to your needs.

## Example 1
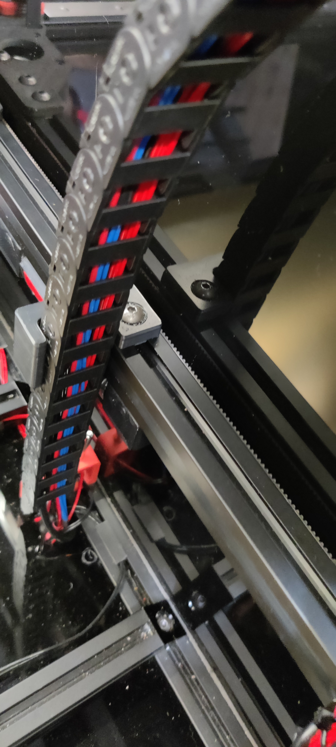
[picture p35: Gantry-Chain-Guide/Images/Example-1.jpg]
Gantry Chain Guide - Example 1


## Example 2
Here's another variation
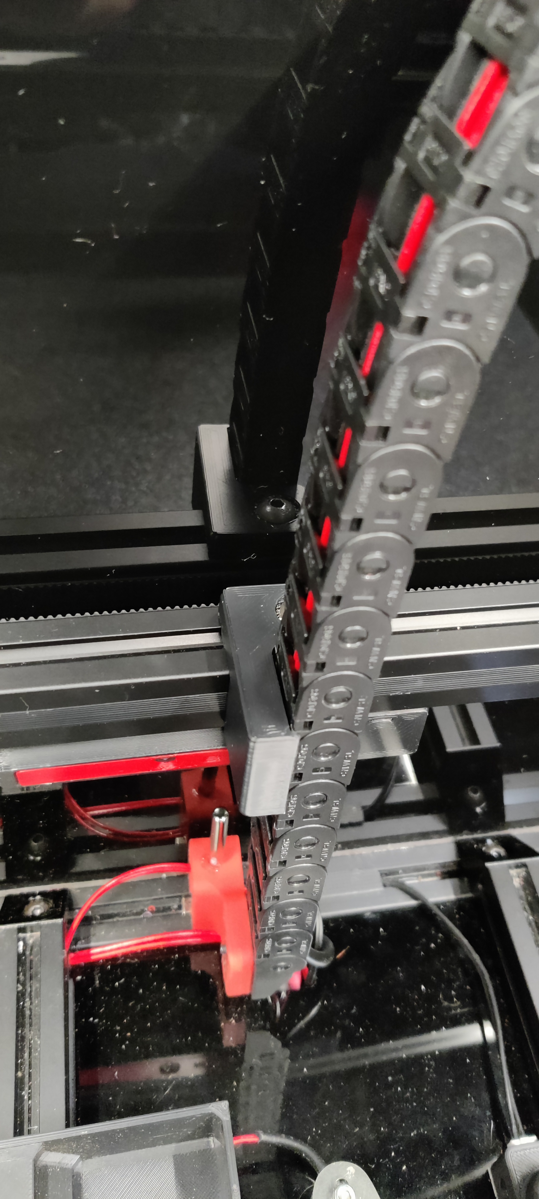
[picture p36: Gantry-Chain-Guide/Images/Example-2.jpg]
Gantry Chain Guide - Example 2


# Models
The check the [CAD](CAD/) and [STL](STL/) folders for the Fusion360 design and the resulting STL model.

# Print Settings
Printed in ABS to cope with heat of chamber.
Used standard Voron ABS print guidance.
Part is already oriented in STL.

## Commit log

2022-12-18 Initial draft check-in
    [base.step, base.stl, cover-arrow-vertical v4.f3d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]
2022-12-19 Added v2 of PCB and 3 variants for number of keys.
2022-12-19 Create buttons.cfg
    Add sample Klipper config
    [buttons.cfg]
2022-12-20 Add AngryCAM models
    [Front_Cover_OV5648_120DEG_AF v13.f3d, Front_Cover_OV5648_120DEG_AF v13.stl]
2022-12-20 Add Gantry Chain Guide
    [Cable Chain Guide for Centre Gantry v9.f3d, Cable Chain Guide for Centre Gantry v9.stl]
2022-12-20 Update README.md
    Link the added content for Angry CAM models and Gantry Chain Guide
2022-12-21 Add some Key Caps
    Additional key caps for Camera, Flame, Light, Pause, Pause+Resume.
    Also a set of key caps with the recesses more deep.
    [cover-arrow-vertical v4.stl, cover-arrow-vertical-dot-dot v2.stl, cover-camera v2.stl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]
2022-12-21 New Key Caps, Photos and Klipper config
    [buttons.cfg]
2022-12-21 Add .F3D CAD models for new Key Caps
    [cover-arrow-vertical-dot-dot v2.f3d, cover-camera v2.f3d, cover-flame v2.f3d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]
2022-12-30 8.5mm Sturdy Handles for clearing 6mm panels
    [sturdy_handles 8.5mm.f3d, sturdy_handles 8.5mm.stl]
2022-12-30 Update README.md
    Add link to Sturdy Handles (that clear 6mm panels)
2022-12-30 Add purge bucket mod
    [Brush Holder Sheet Stop -- Mod.stl, Brush Mount Spacer Shortened.stl, Nozzle_Brush_Assembly_for_Kinematic_Mounts_Jaans v5.f3d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]
2022-12-30 Update README.md
    Link to purge bucket mod and add disclaimer
